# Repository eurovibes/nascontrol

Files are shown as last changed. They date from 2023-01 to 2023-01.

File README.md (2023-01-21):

<!-- SPDX-FileCopyrightText: 2023 Benedikt Spranger <b.spranger@linutronix.de> -->
<!-- SPDX-License-Identifier: CERN-OHL-S-2.0 -->


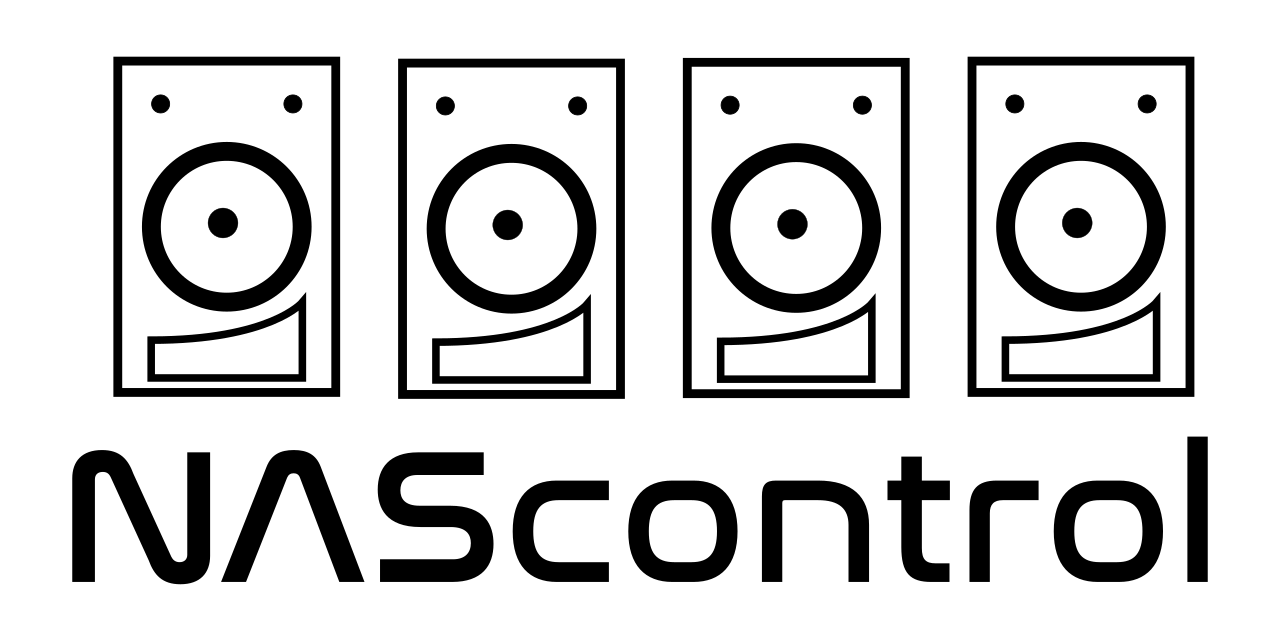
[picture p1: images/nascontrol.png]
NAScontrol logo


# NAScontrol - A NAS control board

## License rules

nascontrol is provided under the terms of the CERN-OHL-S license
version 2 as provided in the LICENSES/CERN-OHL-S-2.0 file.

Instead of adding license boilerplates to the individual files,
nascontrol uses SPDX license identifiers, which are machine parseable
and considered legaly equivalent.

The SPDX license identifier in nascontrol shall be added at the first
possible line in a file which can contain a comment. This is normally the
first line except for scripts. Scripts require the #!PATH_TO_INTERPRETER tag
in the first line; place the SPDX identifier into the second line.

The SPDX license identifier is added in form of a comment.

## Copyright and License

> Copyright Benedikt Spranger 2023.
> This source describes Open Hardware and is licensed under the CERNOHL-S v2.
> You may redistribute and modify this source and make products using it
> under the terms of the CERN-OHL-S v2 (https://ohwr.org/cern ohl s v2.txt ).
> This source is distributed WITHOUT ANY EXPRESS OR IMPLIED WARRANTY, INCLUDING
> OF MERCHANTABILITY, SATISFACTORY QUALITY AND FITNESS FOR A PARTICULAR PURPOSE.
> Please see the CERN-OHL-S v2 for applicable conditions.
> Source location: https://github.com/eurovibes/nascontrol
> As per CERN-OHL-S v2 section 4, should You produce hardware based
> on this source, You must where practicable maintain the Source Location
> visible on the external case of the nascontrol or other products you
> make using this source.

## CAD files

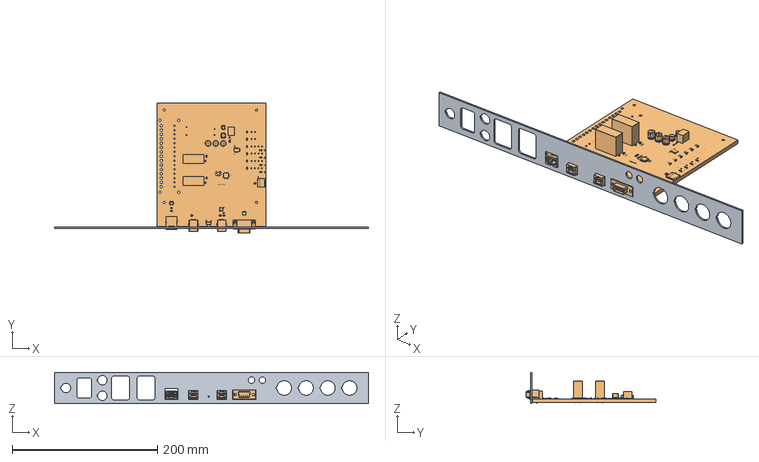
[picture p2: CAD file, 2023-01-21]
enclosure/frontpanel.FCStd
431.8 x 179.3 x 43.0 mm
Frontpanel
nascontrol

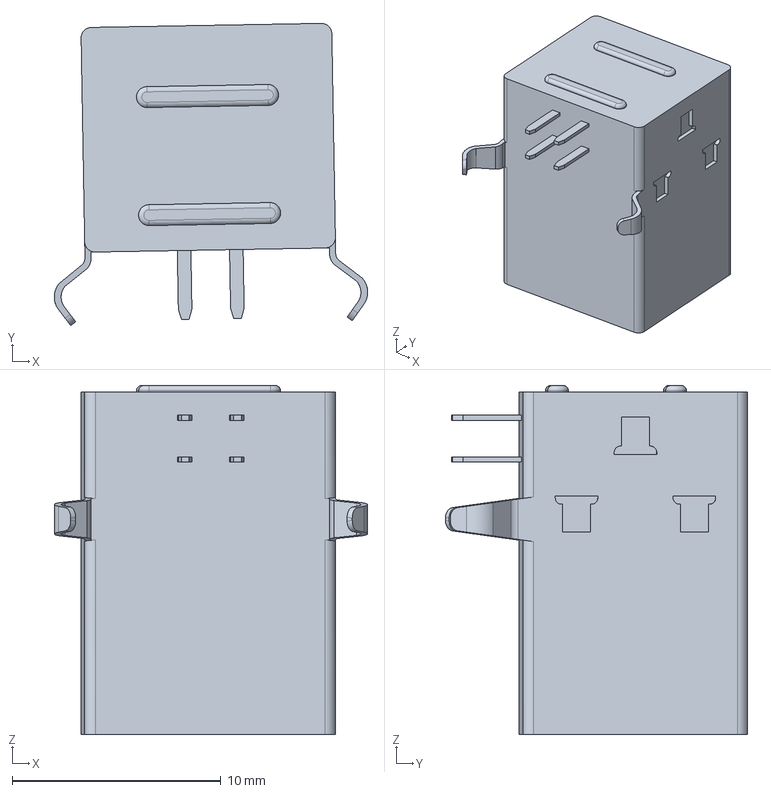
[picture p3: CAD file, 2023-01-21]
3D-model/lumberg_2411_02.stp
15.0 x 14.5 x 16.7 mm

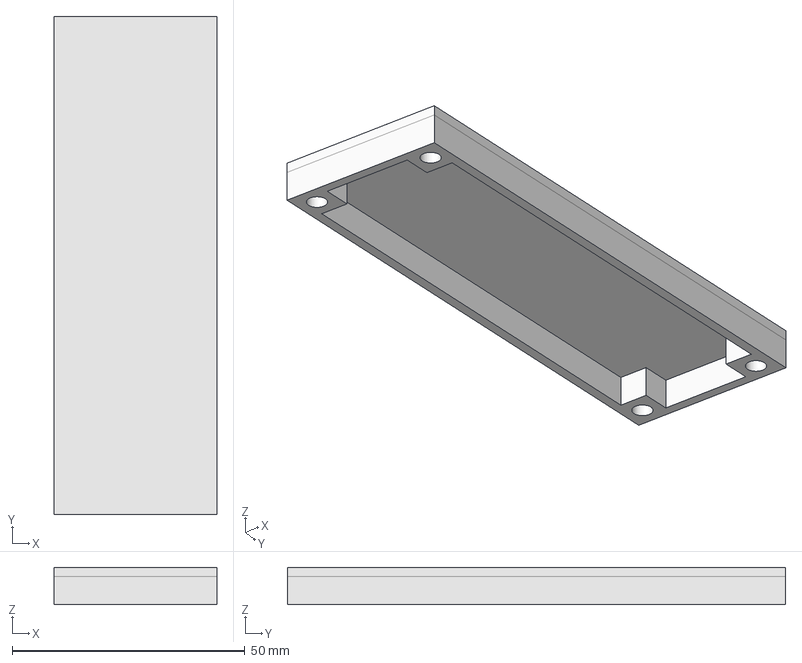
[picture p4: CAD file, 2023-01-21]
enclosure/protector.FCStd
35.0 x 107.0 x 8.00 mm

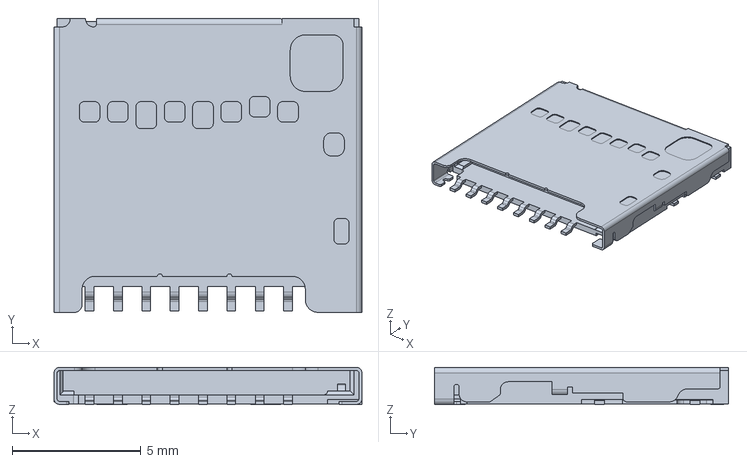
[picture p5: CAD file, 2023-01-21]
3D-model/1040310811.stp
11.9 x 11.4 x 1.45 mm

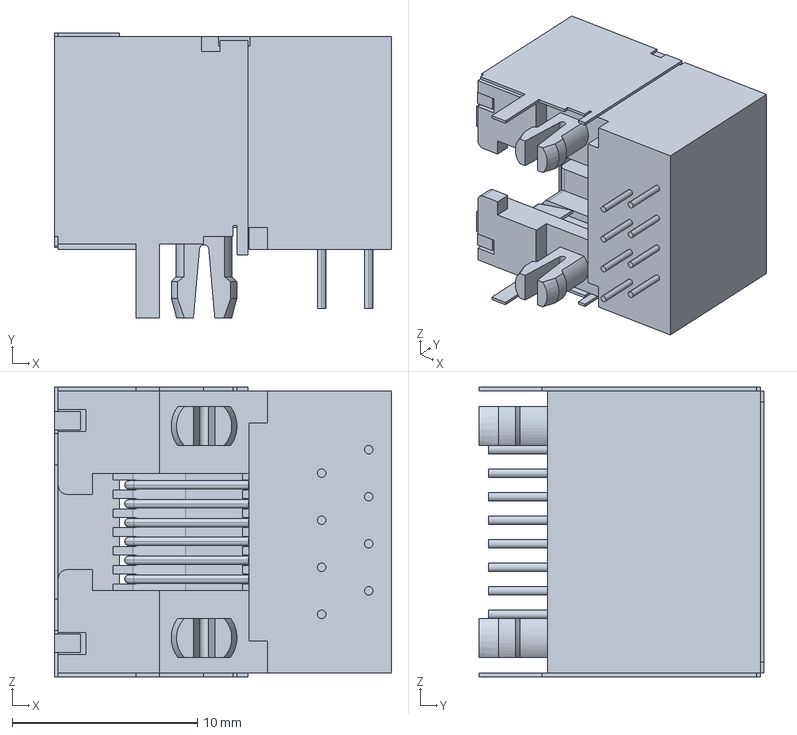
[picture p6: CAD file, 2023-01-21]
3D-model/92250-088LFc.stp
18.2 x 15.4 x 15.6 mm

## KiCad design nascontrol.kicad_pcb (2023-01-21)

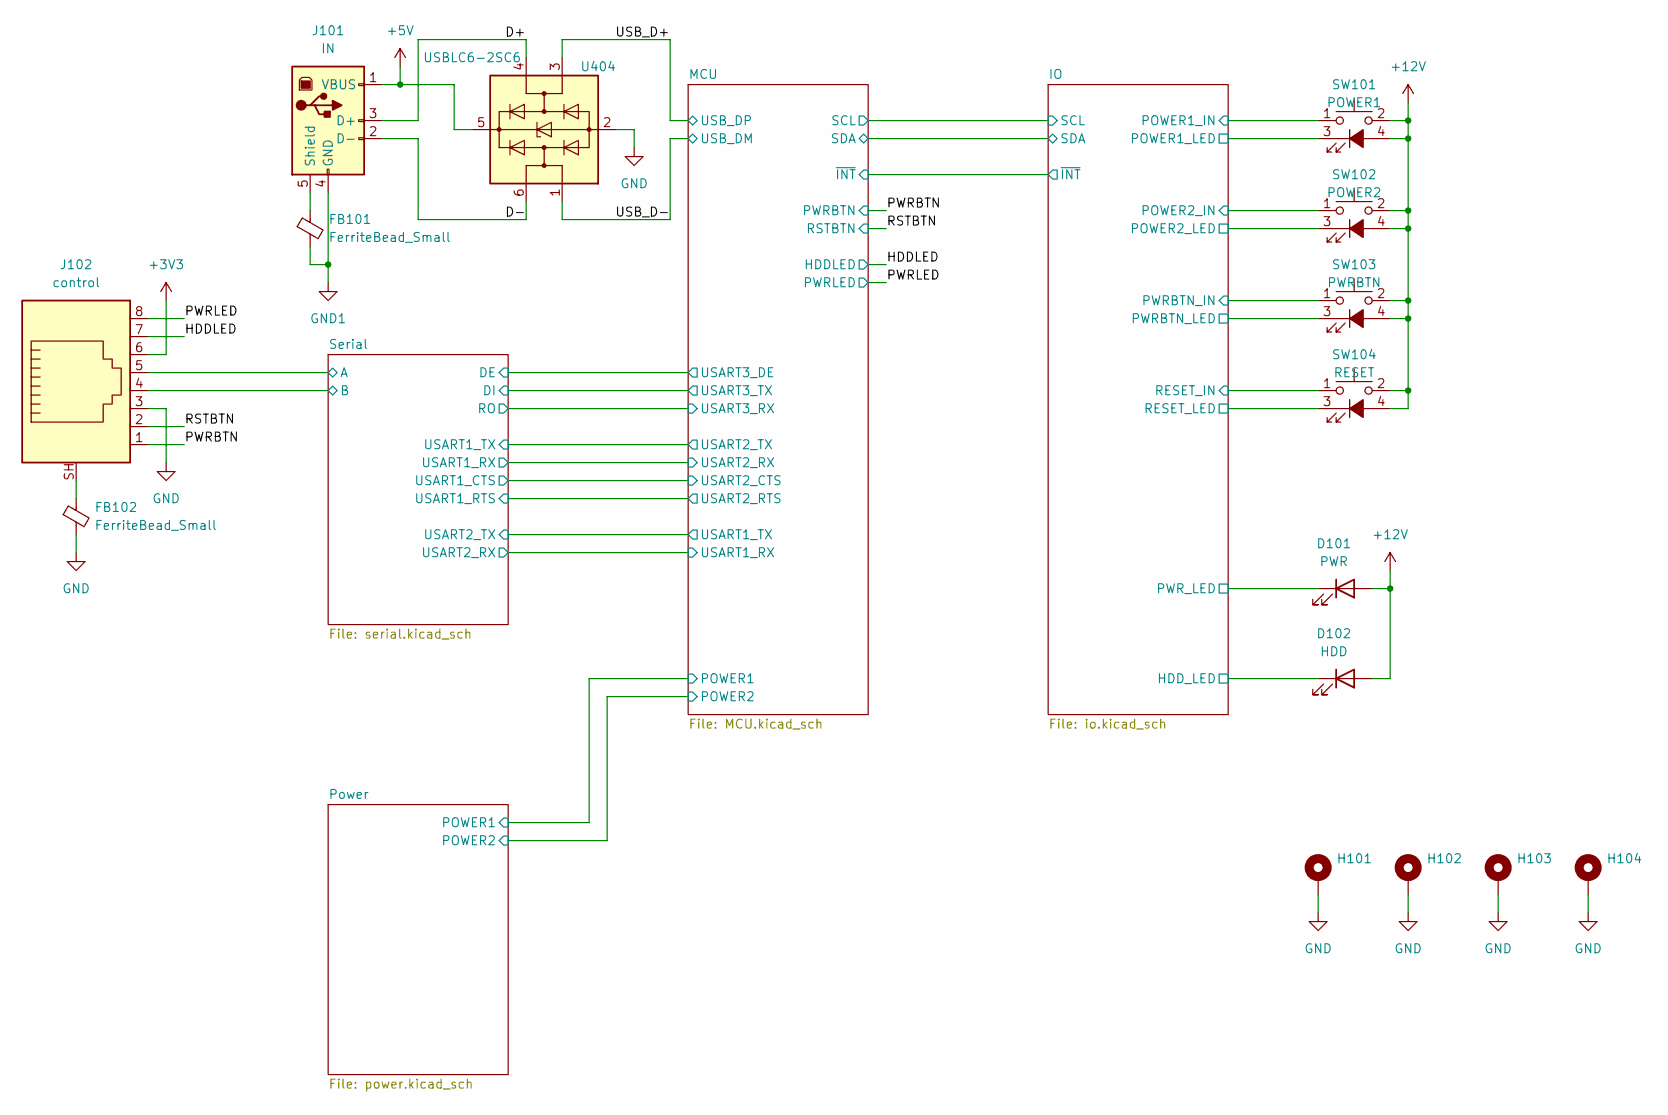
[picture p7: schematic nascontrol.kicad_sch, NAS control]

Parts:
D101: PWR; SolderWire-0.75sqmm_1x02_P4.8mm_D1.25mm_OD2.3mm; mpn N/A
D102: HDD; SolderWire-0.75sqmm_1x02_P4.8mm_D1.25mm_OD2.3mm; mpn N/A
FB101, FB102: FerriteBead_Small; L_0805_2012Metric; mpn GZ2012D101TF; LCSC# C1015
H101, H102, H103, H104: MountingHole_3.2mm_M3_Pad; mpn N/A
J101: IN; USB_B_Lumberg_2411_02_Horizontal; mpn TUEB4F2D0B
J102: control; MTJ-88GX1-FSD-PG6; mpn 6339160-1; LCSC# C125076
SW101: POWER1; SolderWire-0.75sqmm_1x04_P4.8mm_D1.25mm_OD2.3mm; mpn N/A
SW102: POWER2; SolderWire-0.75sqmm_1x04_P4.8mm_D1.25mm_OD2.3mm; mpn N/A
SW103: PWRBTN; SolderWire-0.75sqmm_1x04_P4.8mm_D1.25mm_OD2.3mm; mpn N/A
SW104: RESET; SolderWire-0.75sqmm_1x04_P4.8mm_D1.25mm_OD2.3mm; mpn N/A
U404: USBLC6-2SC6; SOT-23-6; mpn USBLC6-2SC6; LCSC# C2827654

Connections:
+12V: D101.2 (A), D102.2 (A), SW101.2, SW101.4 (A), SW102.2, SW102.4 (A), SW103.2, SW103.4 (A), SW104.2, SW104.4 (A); also elsewhere on the board
/HDDLED: J102.7; also elsewhere on the board
/IO/HDD_LED: D102.1 (K); also elsewhere on the board
/IO/POWER1_IN: SW101.1; also elsewhere on the board
/IO/POWER1_LED: SW101.3 (K); also elsewhere on the board
/IO/POWER2_IN: SW102.1; also elsewhere on the board
/IO/POWER2_LED: SW102.3 (K); also elsewhere on the board
/IO/PWRBTN_IN: SW103.1; also elsewhere on the board
/IO/PWRBTN_LED: SW103.3 (K); also elsewhere on the board
/IO/PWR_LED: D101.1 (K); also elsewhere on the board
/IO/RESET_IN: SW104.1; also elsewhere on the board
/IO/RESET_LED: SW104.3 (K); also elsewhere on the board
/PWRBTN: J102.1; also elsewhere on the board
/PWRLED: J102.8; also elsewhere on the board
/RSTBTN: J102.2; also elsewhere on the board
/Serial/A: J102.5; also elsewhere on the board
/Serial/B: J102.4; also elsewhere on the board
GND: FB102.2, H101.1, H102.1, H103.1, H104.1, J102.3, U404.2 (GND); also elsewhere on the board
GND1: FB101.2, J101.4 (GND); also elsewhere on the board
unnamed: FB101.1, J101.5 (Shield)
unnamed: FB102.1, J102.SH

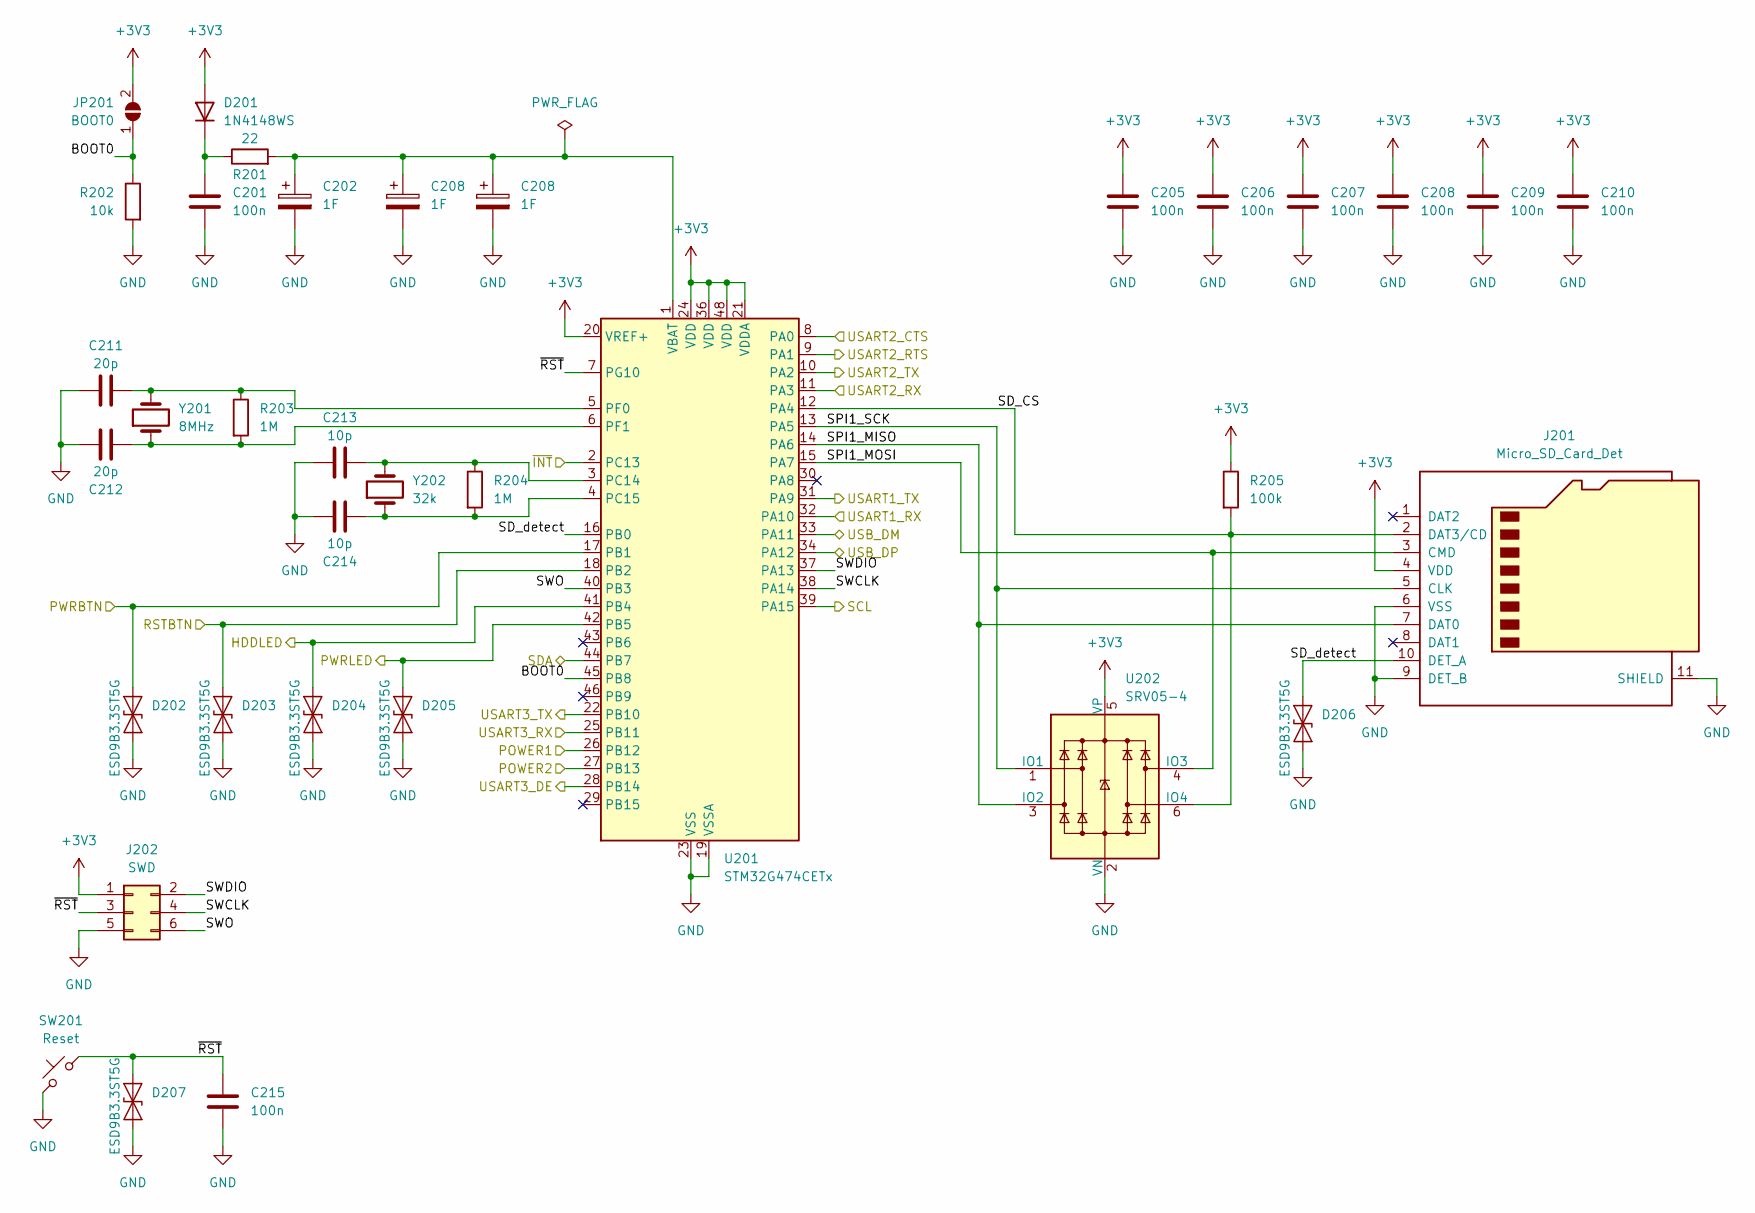
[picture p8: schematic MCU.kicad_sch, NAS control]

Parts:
C201, C205, C206, C207, C209, C210, C215: 100n; C_0402_1005Metric; mpn CL05B104KB54PNC; LCSC# C307331
C202, C208: 1F; CP_Radial_D8.0mm_P3.50mm; mpn SCV0001C0-003R0LTZ
C211, C212: 20p; C_0402_1005Metric; mpn 0402CG200J500NT; LCSC# C1554
C213, C214: 10p; C_0402_1005Metric; mpn CL05C100JB5NNNC; LCSC# C32949
D201: 1N4148WS; D_SOD-323; mpn 1N4148WS; LCSC# C2128
D202, D203, D204, D205, D206, D207: ESD9B3.3ST5G; D_SOD-923; mpn ESD9B3.3ST5G; LCSC# C96512
J201: Micro_SD_Card_Det; microSD_HC_Molex_104031-0811; mpn 1040310811; LCSC# C585350
J202: SWD; Tag-Connect_TC2030-IDC-FP_2x03_P1.27mm_Vertical; mpn TC2030
JP201: BOOT0; SolderJumper-2_P1.3mm_Open_Pad1.0x1.5mm; mpn N/A
R201: 22; R_1206_3216Metric; mpn 1206W4F220JT5E; LCSC# C17958
R202: 10k; R_0402_1005Metric; mpn 0402WGF1002TCE; LCSC# C25744
R203, R204: 1M; R_0402_1005Metric; mpn 0402WGF1004TCE; LCSC# C26083
R205: 100k; R_0402_1005Metric; mpn 0402WGF1003TCE; LCSC# C25741
SW201: Reset; SW_Tactile_SPST_Angled_PTS645Vx58-2LFS; mpn PTS645VL58-2 LFS
U201: STM32G474CETx; LQFP-48_7x7mm_P0.5mm; mpn STM32G474CET6; LCSC# C730125
U202: SRV05-4; SOT-23-6; mpn SRV05-4; LCSC# C558418
Y201: 8MHz; Crystal_SMD_5032-2Pin_5.0x3.2mm; mpn X50328MSB2GI; LCSC# C115962
Y202: 32k; Crystal_SMD_3215-2Pin_3.2x1.5mm; mpn Q13FC1350000400; LCSC# C32346

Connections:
/HDDLED: D204.2 (A2), U201.41 (PB4); also elsewhere on the board
/IO/SCL: U201.39 (PA15); also elsewhere on the board
/IO/SDA: U201.44 (PB7); also elsewhere on the board
/IO/~INT: U201.2 (PC13); also elsewhere on the board
/MCU/BOOT0: JP201.1 (A), R202.1, U201.45 (PB8)
/MCU/POWER1: U201.26 (PB12); also elsewhere on the board
/MCU/POWER2: U201.27 (PB13); also elsewhere on the board
/MCU/SD_CS: J201.2 (DAT3/CD), R205.2, U201.12 (PA4), U202.6 (IO4)
/MCU/SD_detect: D206.2 (A2), J201.10 (DET_A), U201.16 (PB0)
/MCU/SPI1_MISO: J201.7 (DAT0), U201.14 (PA6), U202.3 (IO2)
/MCU/SPI1_MOSI: J201.3 (CMD), U201.15 (PA7), U202.4 (IO3)
/MCU/SPI1_SCK: J201.5 (CLK), U201.13 (PA5), U202.1 (IO1)
/MCU/SWCLK: J202.4, U201.38 (PA14)
/MCU/SWDIO: J202.2, U201.37 (PA13)
/MCU/SWO: J202.6, U201.40 (PB3)
/MCU/USART1_RX: U201.32 (PA10); also elsewhere on the board
/MCU/USART1_TX: U201.31 (PA9); also elsewhere on the board
/MCU/USART2_CTS: U201.8 (PA0); also elsewhere on the board
/MCU/USART2_RTS: U201.9 (PA1); also elsewhere on the board
/MCU/USART2_RX: U201.11 (PA3); also elsewhere on the board
/MCU/USART2_TX: U201.10 (PA2); also elsewhere on the board
/MCU/USART3_DE: U201.28 (PB14); also elsewhere on the board
/MCU/USART3_RX: U201.25 (PB11); also elsewhere on the board
/MCU/USART3_TX: U201.22 (PB10); also elsewhere on the board
/MCU/~RST: C215.1, D207.2 (A2), J202.3, SW201.1, U201.7 (PG10)
/PWRBTN: D202.2 (A2), U201.17 (PB1); also elsewhere on the board
/PWRLED: D205.2 (A2), U201.42 (PB5); also elsewhere on the board
/RSTBTN: D203.2 (A2), U201.18 (PB2); also elsewhere on the board
GND: C201.2, C202.2, C205.2, C206.2, C207.2, C208.2, C209.2, C210.2, C211.1, C212.1, C213.1, C214.1, C215.2, D202.1 (A1), D203.1 (A1), D204.1 (A1), D205.1 (A1), D206.1 (A1), D207.1 (A1), J201.6 (VSS), J201.9 (DET_B), J201.11 (SHIELD), J202.5, R202.2, SW201.2, U201.19 (VSSA), U201.23 (VSS), U201.35 (VSS), U201.47 (VSS), U202.2 (VN); also elsewhere on the board
unnamed: C201.1, D201.1 (K), R201.1
unnamed: C211.2, R203.1, U201.5 (PF0), Y201.2
unnamed: C212.2, R203.2, U201.6 (PF1), Y201.1
unnamed: C213.2, R204.1, U201.3 (PC14), Y202.2
unnamed: C214.2, R204.2, U201.4 (PC15), Y202.1

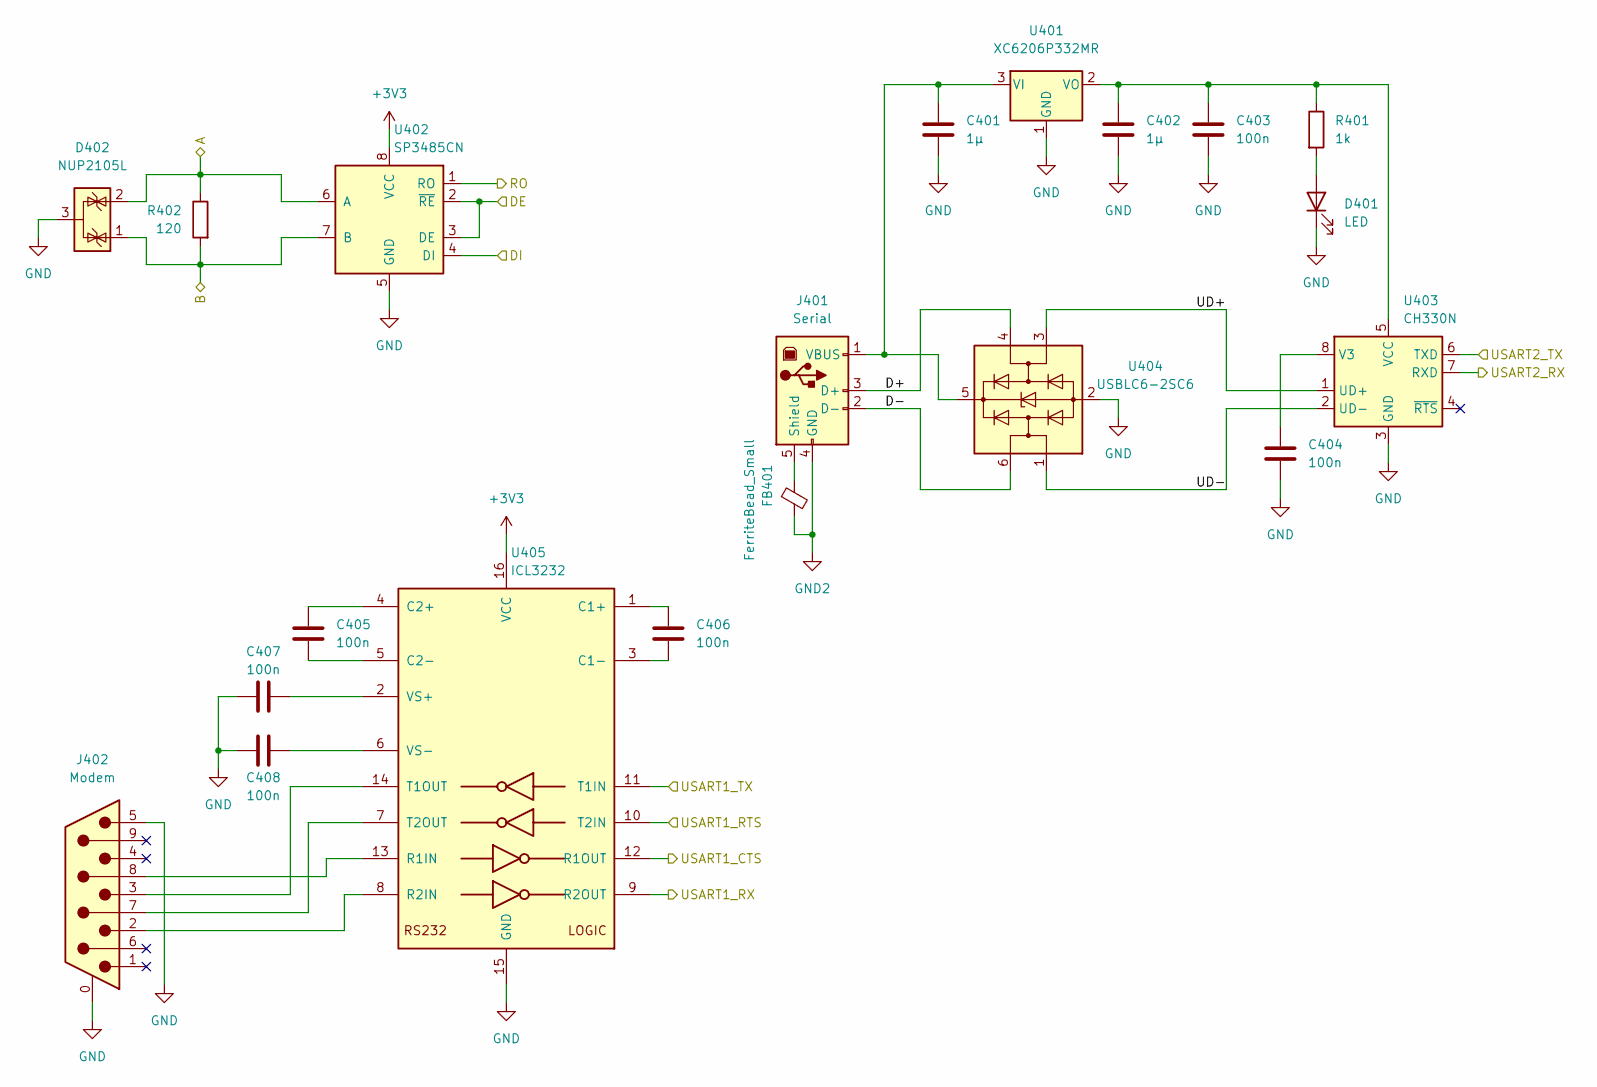
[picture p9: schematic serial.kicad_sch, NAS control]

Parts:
C401, C402: 1µ; C_0805_2012Metric; mpn CL21B105KBFNNNE; LCSC# C28323
C403, C404, C405, C406, C407, C408: 100n; C_0402_1005Metric; mpn CL05B104KB54PNC; LCSC# C307331
D401: LED; LED_0603_1608Metric; mpn 19-217/GHC-YR1S2/3T; LCSC# C72043
D402: NUP2105L; SOT-23; mpn NUP2105LT1G; LCSC# C2890118
FB401: FerriteBead_Small; L_0805_2012Metric; mpn GZ2012D101TF; LCSC# C1015
J401: Serial; USB_B_Lumberg_2411_02_Horizontal; mpn TUEB4F2D0B
J402: Modem; DSUB-9_Male_Horizontal_P2.77x2.84mm_EdgePinOffset7.70mm_Hou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; mpn DE09-PL-24
R401: 1k; R_0402_1005Metric; mpn 0402WGF1001TCE; LCSC# C11702
R402: 120; R_1206_3216Metric; mpn 1206W4F1200T5E; LCSC# C17909
U401: XC6206P332MR; SOT-23; mpn XC6206P332MR; LCSC# C5446
U402: SP3485CN; SOIC-8_3.9x4.9mm_P1.27mm; mpn SP3485EN-L/TR; LCSC# C8963
U403: CH330N; SOIC-8_3.9x4.9mm_P1.27mm; mpn CH340N; LCSC# C506813
U404: USBLC6-2SC6; SOT-23-6; mpn USBLC6-2SC6; LCSC# C2827654
U405: ICL3232; TSSOP-16_4.4x5mm_P0.65mm; mpn SP3232EEY-L/TR; LCSC# C13482

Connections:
/MCU/USART1_RX: U403.7 (RXD); also elsewhere on the board
/MCU/USART1_TX: U403.6 (TXD); also elsewhere on the board
/MCU/USART2_CTS: U405.12 (R1OUT); also elsewhere on the board
/MCU/USART2_RTS: U405.10 (T2IN); also elsewhere on the board
/MCU/USART2_RX: U405.9 (R2OUT); also elsewhere on the board
/MCU/USART2_TX: U405.11 (T1IN); also elsewhere on the board
/MCU/USART3_DE: U402.2 (~RE), U402.3 (DE); also elsewhere on the board
/MCU/USART3_RX: U402.1 (RO); also elsewhere on the board
/MCU/USART3_TX: U402.4 (DI); also elsewhere on the board
/Serial/A: D402.2 (K), R402.1, U402.6 (A); also elsewhere on the board
/Serial/B: D402.1 (K), R402.2, U402.7 (B); also elsewhere on the board
GND: C401.2, C402.2, C403.2, C404.2, C407.1, C408.1, D401.1 (K), D402.3 (A), J402.0 (PAD), J402.5, U401.1 (GND), U402.5 (GND), U403.3 (GND), U404.2 (GND), U405.15 (GND); also elsewhere on the board
GND2: FB401.2, J401.4 (GND); also elsewhere on the board
unnamed: C402.1, C403.1, R401.1, U401.2 (VO), U403.5 (VCC)
unnamed: C404.1, U403.8 (V3)
unnamed: C405.1, U405.4 (C2+)
unnamed: C405.2, U405.5 (C2-)
unnamed: C406.1, U405.1 (C1+)
unnamed: C406.2, U405.3 (C1-)
unnamed: C407.2, U405.2 (VS+)
unnamed: C408.2, U405.6 (VS-)
unnamed: D401.2 (A), R401.2
unnamed: FB401.1, J401.5 (Shield)
unnamed: J402.2, U405.8 (R2IN)
unnamed: J402.3, U405.14 (T1OUT)
unnamed: J402.7, U405.7 (T2OUT)
unnamed: J402.8, U405.13 (R1IN)

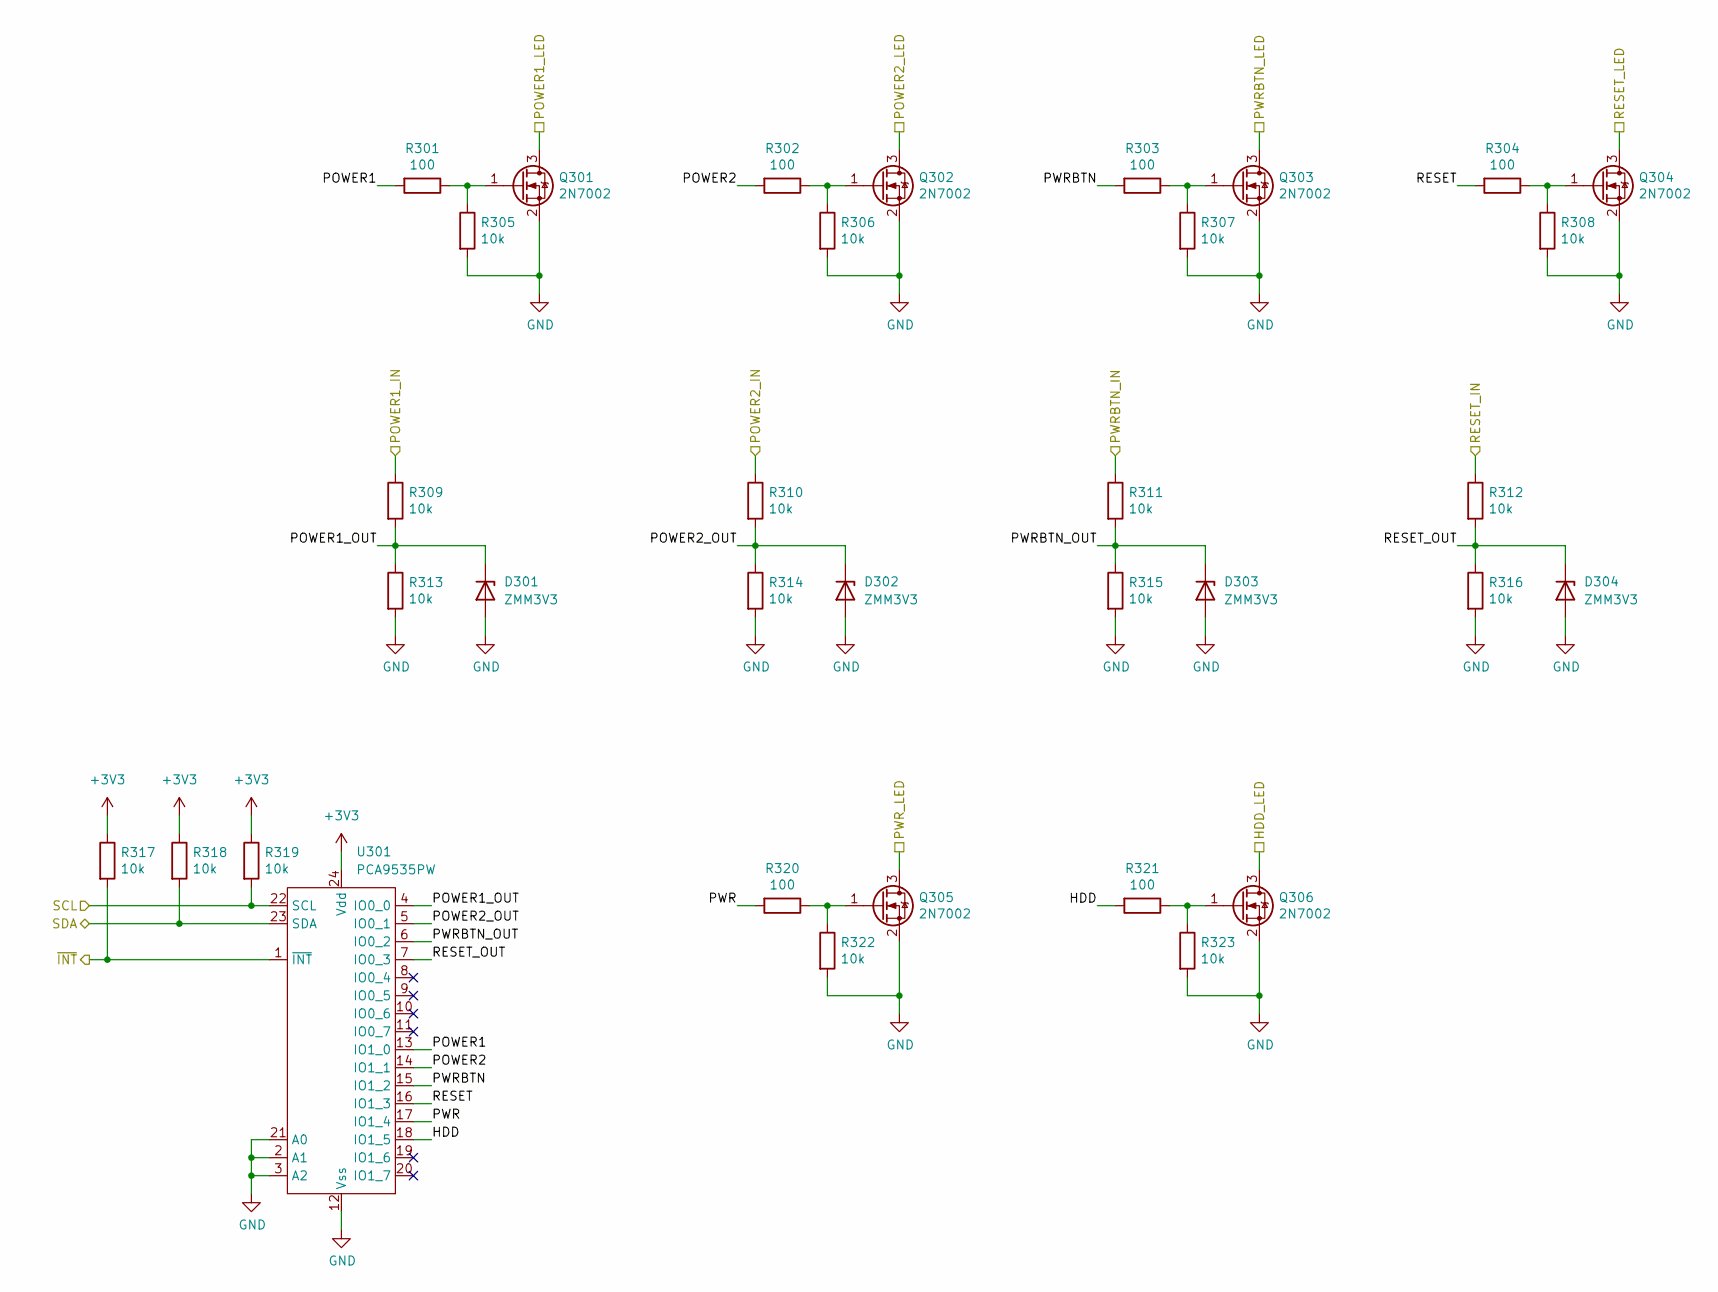
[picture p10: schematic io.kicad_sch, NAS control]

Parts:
D301, D302, D303, D304: ZMM3V3; D_MiniMELF; mpn ZMM3V3-M; LCSC# C8056
Q301, Q302, Q303, Q304, Q305, Q306: 2N7002; SOT-23; mpn 2N7002; LCSC# C8545
R301, R302, R303, R304, R320, R321: 100; R_0402_1005Metric; mpn 0402WGF1000TCE; LCSC# C25076
R305, R306, R307, R308, R309, R310, R311, R312, R313, R314, R315, R316, R317, R318, R319, R322, R323: 10k; R_0402_1005Metric; mpn 0402WGF1002TCE; LCSC# C25744
U301: PCA9535PW; TSSOP-24_4.4x7.8mm_P0.65mm; mpn PCA9535PW,118; LCSC# C255606

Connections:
/IO/HDD: R321.2, U301.18 (IO1_5)
/IO/HDD_LED: Q306.3 (D); also elsewhere on the board
/IO/POWER1: R301.2, U301.13 (IO1_0)
/IO/POWER1_IN: R309.1; also elsewhere on the board
/IO/POWER1_LED: Q301.3 (D); also elsewhere on the board
/IO/POWER1_OUT: D301.1 (K), R309.2, R313.1, U301.4 (IO0_0)
/IO/POWER2: R302.2, U301.14 (IO1_1)
/IO/POWER2_IN: R310.1; also elsewhere on the board
/IO/POWER2_LED: Q302.3 (D); also elsewhere on the board
/IO/POWER2_OUT: D302.1 (K), R310.2, R314.1, U301.5 (IO0_1)
/IO/PWR: R320.2, U301.17 (IO1_4)
/IO/PWRBTN: R303.2, U301.15 (IO1_2)
/IO/PWRBTN_IN: R311.1; also elsewhere on the board
/IO/PWRBTN_LED: Q303.3 (D); also elsewhere on the board
/IO/PWRBTN_OUT: D303.1 (K), R311.2, R315.1, U301.6 (IO0_2)
/IO/PWR_LED: Q305.3 (D); also elsewhere on the board
/IO/RESET: R304.2, U301.16 (IO1_3)
/IO/RESET_IN: R312.1; also elsewhere on the board
/IO/RESET_LED: Q304.3 (D); also elsewhere on the board
/IO/RESET_OUT: D304.1 (K), R312.2, R316.1, U301.7 (IO0_3)
/IO/SCL: R319.2, U301.22 (SCL); also elsewhere on the board
/IO/SDA: R318.2, U301.23 (SDA); also elsewhere on the board
/IO/~INT: R317.2, U301.1 (~INT); also elsewhere on the board
GND: D301.2 (A), D302.2 (A), D303.2 (A), D304.2 (A), Q301.2 (S), Q302.2 (S), Q303.2 (S), Q304.2 (S), Q305.2 (S), Q306.2 (S), R305.2, R306.2, R307.2, R308.2, R313.2, R314.2, R315.2, R316.2, R322.2, R323.2, U301.2 (A1), U301.3 (A2), U301.12 (Vss), U301.21 (A0); also elsewhere on the board
unnamed: Q301.1 (G), R301.1, R305.1
unnamed: Q302.1 (G), R302.1, R306.1
unnamed: Q303.1 (G), R303.1, R307.1
unnamed: Q304.1 (G), R304.1, R308.1
unnamed: Q305.1 (G), R320.1, R322.1
unnamed: Q306.1 (G), R321.1, R323.1

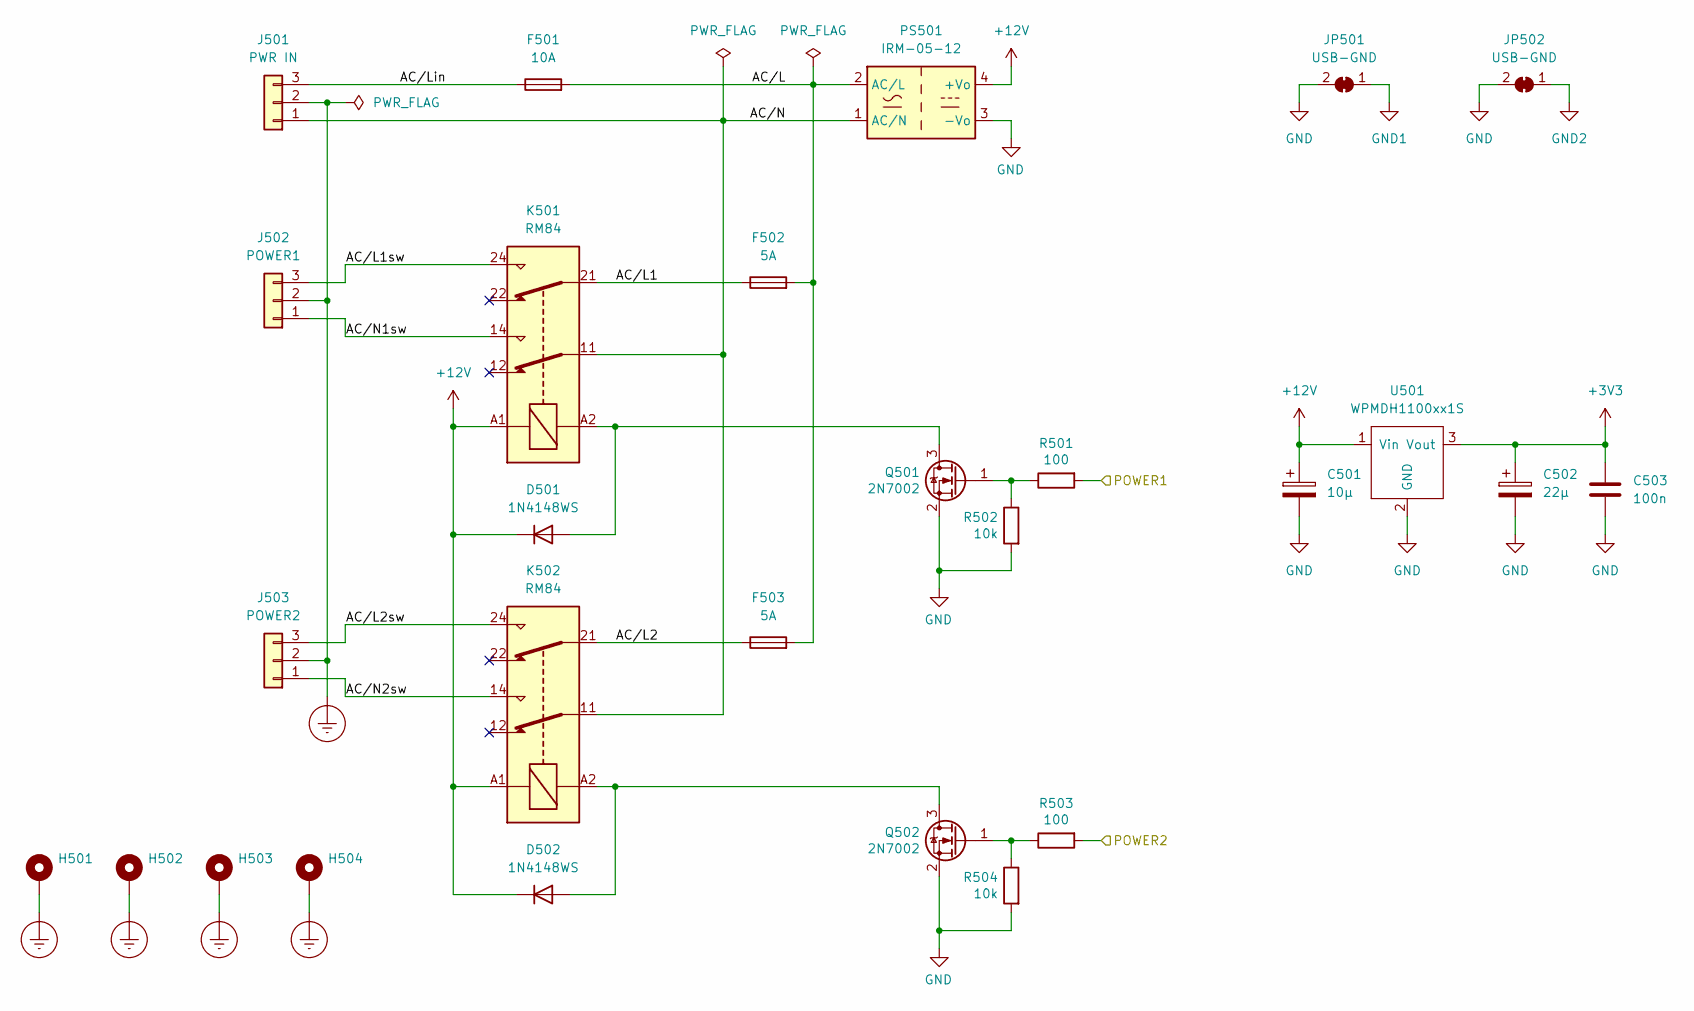
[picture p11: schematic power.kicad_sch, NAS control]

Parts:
C501: 10µ; CP_Elec_5x5.4; mpn RVT1H100M0505; LCSC# C72487
C502: 22µ; CP_Elec_6.3x5.4; mpn RVT1H220M0605; LCSC# C72505
C503: 100n; C_0402_1005Metric; mpn CL05B104KB54PNC; LCSC# C307331
D501, D502: 1N4148WS; D_SOD-323; mpn 1N4148WS; LCSC# C2128
F501: 10A; SolderWire-1.5sqmm_1x02_P6mm_D1.7mm_OD3mm_Relief; mpn R3-12E
F502, F503: 5A; SolderWire-1.5sqmm_1x02_P6mm_D1.7mm_OD3mm_Relief; mpn R3-12E
H501, H502, H503, H504: MountingHole_3.2mm_M3_Pad
J501: PWR IN; SolderWire-1.5sqmm_1x03_P6mm_D1.7mm_OD3mm_Relief; mpn N/A
J502: POWER1; SolderWire-1.5sqmm_1x03_P6mm_D1.7mm_OD3mm_Relief; mpn N/A
J503: POWER2; SolderWire-1.5sqmm_1x03_P6mm_D1.7mm_OD3mm_Relief; mpn N/A
JP501, JP502: USB-GND; SolderJumper-2_P1.3mm_Bridged2Bar_Pad1.0x1.5mm; mpn N/A
K501, K502: RM84; Relay_DPDT_Finder_40.52; mpn RM84-2012-35-1012
PS501: IRM-05-12; Converter_ACDC_MeanWell_IRM-05-xx_THT; mpn IRM-05-12
Q501, Q502: 2N7002; SOT-23; mpn 2N7002; LCSC# C8545
R501, R503: 100; R_0402_1005Metric; mpn 0402WGF1000TCE; LCSC# C25076
R502, R504: 10k; R_0402_1005Metric; mpn 0402WGF1002TCE; LCSC# C25744
U501: WPMDH1100xx1S; mpn AMSRB1-783.3JZ

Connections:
+12V: C501.1, D501.1 (K), D502.1 (K), K501.A1, K502.A1, PS501.4 (+Vo), U501.1 (Vin); also elsewhere on the board
/MCU/POWER1: R501.2; also elsewhere on the board
/MCU/POWER2: R503.2; also elsewhere on the board
/Power/AC/L: F501.2, F502.2, F503.2, PS501.2 (AC/L)
/Power/AC/L1: F502.1, K501.21
/Power/AC/L1sw: J502.3, K501.24
/Power/AC/L2: F503.1, K502.21
/Power/AC/L2sw: J503.3, K502.24
/Power/AC/Lin: F501.1, J501.3
/Power/AC/N: J501.1, K501.11, K502.11, PS501.1 (AC/N)
/Power/AC/N1sw: J502.1, K501.14
/Power/AC/N2sw: J503.1, K502.14
Earth_Protective: H501.1, H502.1, H503.1, H504.1, J501.2, J502.2, J503.2
GND: C501.2, C502.2, C503.2, JP501.2 (B), JP502.2 (B), PS501.3 (-Vo), Q501.2 (S), Q502.2 (S), R502.2, R504.2, U501.2 (GND); also elsewhere on the board
GND1: JP501.1 (A); also elsewhere on the board
GND2: JP502.1 (A); also elsewhere on the board
unnamed: D501.2 (A), K501.A2, Q501.3 (D)
unnamed: D502.2 (A), K502.A2, Q502.3 (D)
unnamed: Q501.1 (G), R501.1, R502.1
unnamed: Q502.1 (G), R503.1, R504.1

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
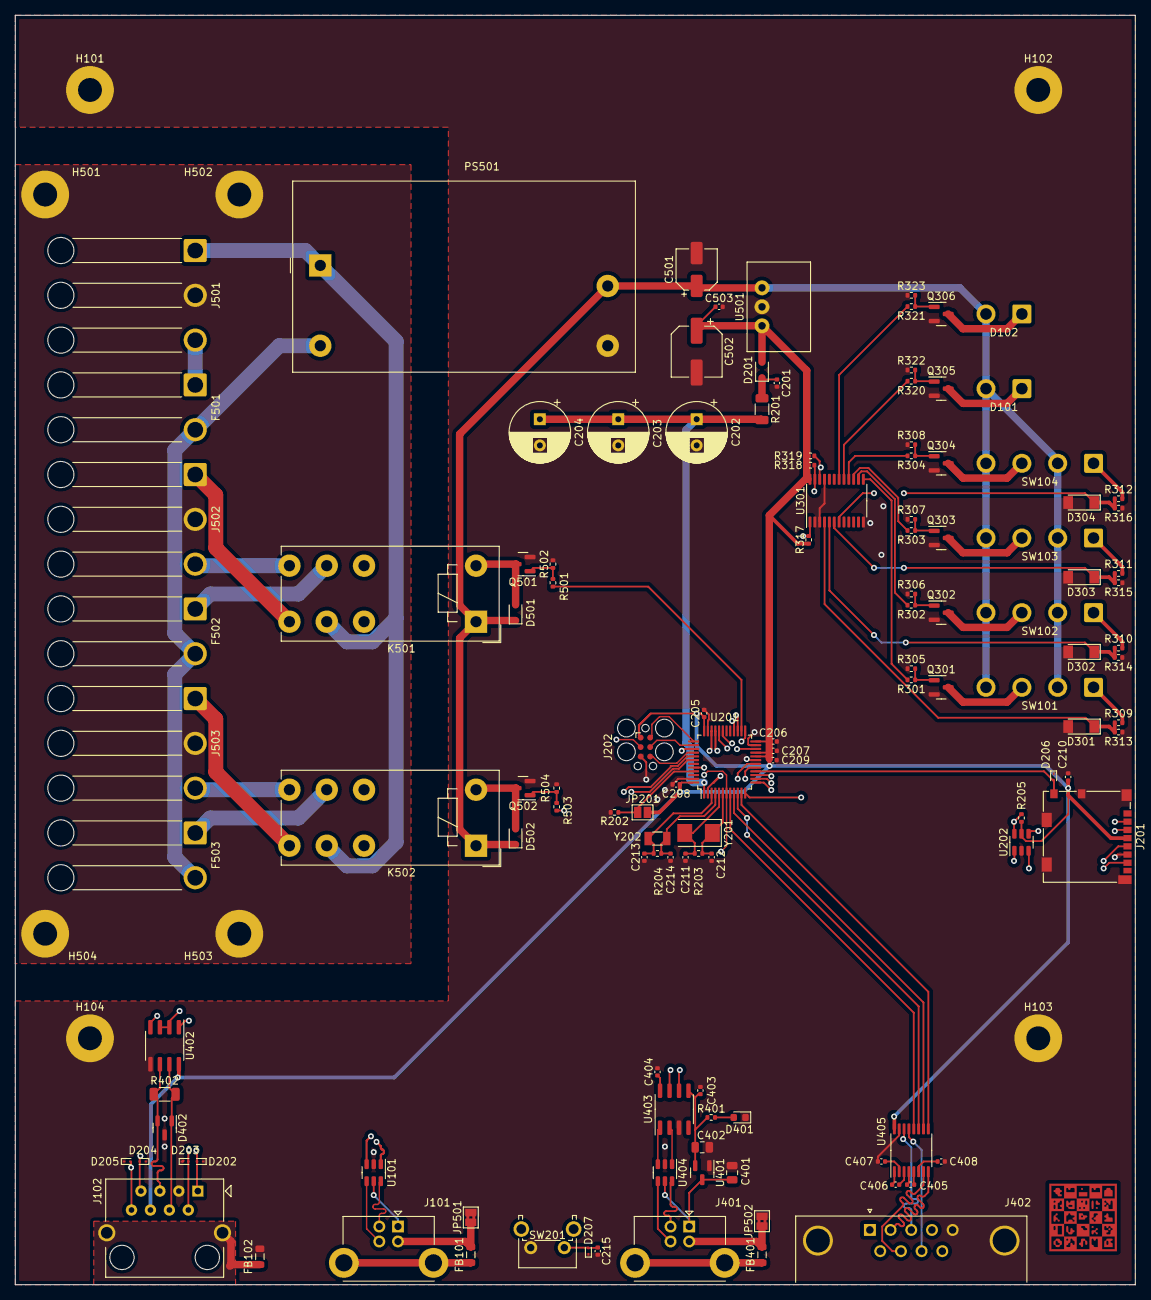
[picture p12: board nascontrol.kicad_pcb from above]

Board: 4 copper layers, 150.0 x 170.0 mm, 131 parts (0 on the bottom side), 107 nets.

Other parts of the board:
C208#2: 100n; C_0402_1005Metric
C208#3: 1F; CP_Radial_D8.0mm_P3.50mm
U404#2: USBLC6-2SC6; SOT-23-6

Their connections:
GND: C208#2.2, C208#3.2, U404#2.2 (GND); also elsewhere on the board

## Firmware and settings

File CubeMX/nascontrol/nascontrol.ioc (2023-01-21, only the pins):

Mcu.UserName=STM32G474CETx
PA0.Signal=USART2_CTS
PA1.Signal=USART2_RTS
PA10.Signal=USART1_RX
PA11.Signal=USB_DM
PA12.Signal=USB_DP
PA13.Signal=SYS_JTMS-SWDIO
PA14.Signal=SYS_JTCK-SWCLK
PA2.Signal=USART2_TX
PA3.Signal=USART2_RX
PA4.GPIO_Label=SD_CS
PA4.Signal=GPIO_Output
PA5.Signal=SPI1_SCK
PA6.Signal=SPI1_MISO
PA7.Signal=SPI1_MOSI
PA9.Signal=USART1_TX
PB0.GPIO_Label=SD_detect
PB0.Signal=GPXTI0
PB1.GPIO_Label=PWRBTN
PB1.Signal=GPXTI1
PB10.Signal=USART3_TX
PB11.Signal=USART3_RX
PB12.GPIO_Label=POWER1
PB12.Signal=GPIO_Output
PB13.GPIO_Label=POWER2
PB13.Signal=GPIO_Output
PB14.Signal=USART3_DE
PB2.GPIO_Label=RSTBTN
PB2.Signal=GPXTI2
PB3.Signal=SYS_JTDO-SWO
PB4.GPIO_Label=HDDLED
PB4.Signal=GPIO_Output
PB5.GPIO_Label=PWRLED
PB5.Signal=GPIO_Output
PB7.Signal=I2C1_SDA
PB8-BOOT0.Signal=I2C1_SCL
PC13.Signal=SYS_WKUP2
PC14-OSC32_IN.Signal=RCC_OSC32_IN
PC15-OSC32_OUT.Signal=RCC_OSC32_OUT
PF0-OSC_IN.Signal=RCC_OSC_IN
PF1-OSC_OUT.Signal=RCC_OSC_OUT

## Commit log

2023-01-21 Update node 12 actions
    Node 12 is EOL. Update Actions relaying on Node 12 to newer versions.
2023-01-21 Add high voltage protector enclosure
    [protector.FCStd]
2023-01-21 Add frontpanel
    [frontpanel.FCStd]

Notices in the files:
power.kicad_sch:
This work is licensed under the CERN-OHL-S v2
